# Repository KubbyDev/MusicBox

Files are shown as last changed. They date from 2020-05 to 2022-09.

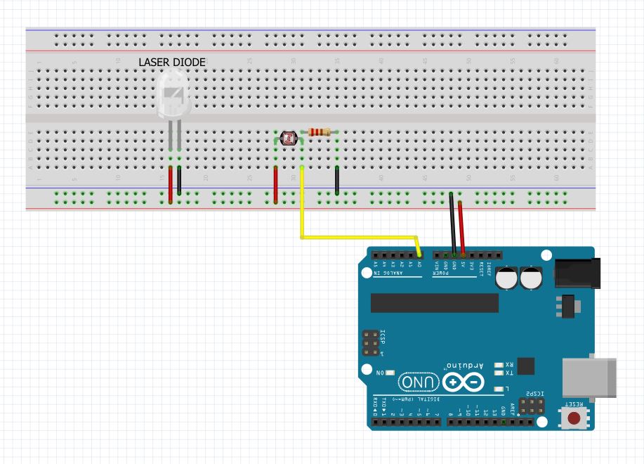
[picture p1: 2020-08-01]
Modules/LaserHarp/Tests/LaserDetection/Circuit.JPG

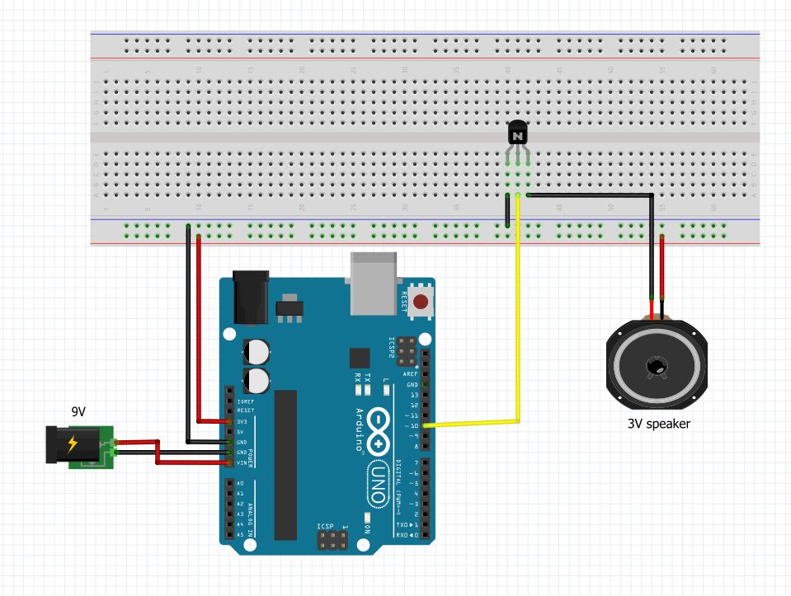
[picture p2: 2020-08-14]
Modules/LaserHarp/Tests/Synthesizing/Circuit.JPG

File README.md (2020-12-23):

# MusicBox

A Music box with only dumb/homemade instruments. Currently I plan on making 5 instruments. All these instruments will be played automatically by the music box from preprocessed files.

### Stepper motors

First prototype done  
Stepper motors (https://www.youtube.com/watch?v=ITn78aMlu0w "Stepper motors")

### Drum

Prototype code is ready to be tested

### Slide Whistle

Some simple prototypes were made but without sufficient performances for the moment.

### Tesla tower

Nothing for the moment

### Laser harp

First prototype in progress

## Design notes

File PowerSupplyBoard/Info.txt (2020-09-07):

General info: 
https://electronics.stackexchange.com/questions/34745/choosing-power-supply-how-to-get-the-voltage-and-current-ratings
Stepper motors: 
https://www.pololu.com/product/1182
http://blog.inventables.com/p/stepper-motors.html

Stepper motors: ---------------------------------------------------------------

Refs:
Quimat 17hd48002h-22b: https://www.amazon.fr/gp/product/B06XQWMDWT/ref=ox_sc_act_title_6?smid=A1WTMON4PWYMJU&psc=1
Longruner A4988: https://www.amazon.fr/gp/product/B071P41ZBW/ref=ox_sc_act_title_1?smid=A1QYNW8GSP8HVC&psc=1

Motor driver:
Voltage for motor: 8V to 35V *
Voltage for logic: 3.3V or 5V
Current draw: 0.5A **
With 3 motors in parallel and a 12V supply, it only draws 0.6A from the supply :shrug:

(*):
There can be voltage spikes higher than 35V, even with a 12V power supply 
These spikes can damage the board. To reduce that risk, connect vmot and gnd with
a 47µF or more capacitor

(**) IMPORTANT: 
Tweak the potentiometer to set the max current (Rsense = 0.1 Ohm)
(read current limiting section: https://www.pololu.com/product/1182)
The value of 0.5A is less than the max (1.7A) and sufficient to get decent melodies

Big Servos --------------------------------------------------------------------

Refs: 
Morza MG996R: https://www.amazon.fr/gp/product/B07KFBWSSW/ref=ox_sc_act_title_3?smid=A3764XWR7FEFWJ&psc=1

Voltage: 4.8V to 7.2V
Current (my measures, 6V): 1A (no load) 2A (stall)

Important: Servo GND and logic GND must be connected

Small Servos ------------------------------------------------------------------

Refs:
SG90

Voltage: 4.8V to 6.0V (best: 5V)
Current (my measures, 5V): 250mA (no load), 700mA (stall)

Important: Servo GND and logic GND must be connected

Laser diodes ------------------------------------------------------------------

Refs:
CESFONJER 650nm 5mW: https://www.amazon.fr/WPERSUVV-Laser-diode-T%C3%AAte-Rouge/dp/B07RM3RWSF

Voltage: 5V
Current (my measures, 5V): 33mA (0.4A for all 12 lasers)

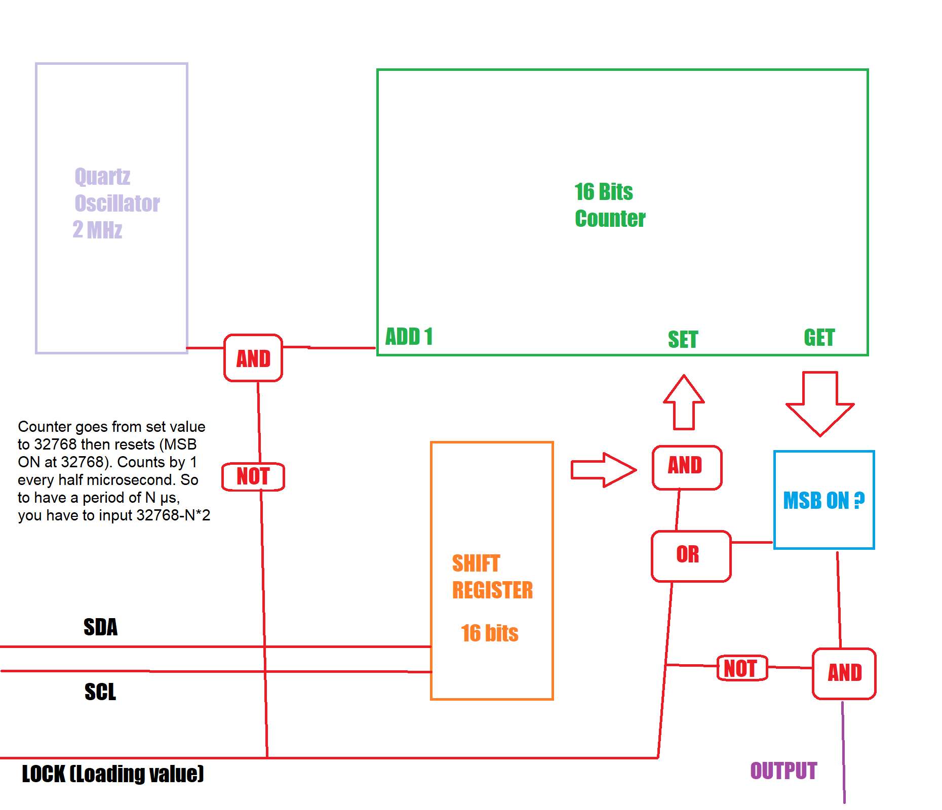
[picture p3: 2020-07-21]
Modules/StepperMotors/OscillatorBoard/Concept2.png

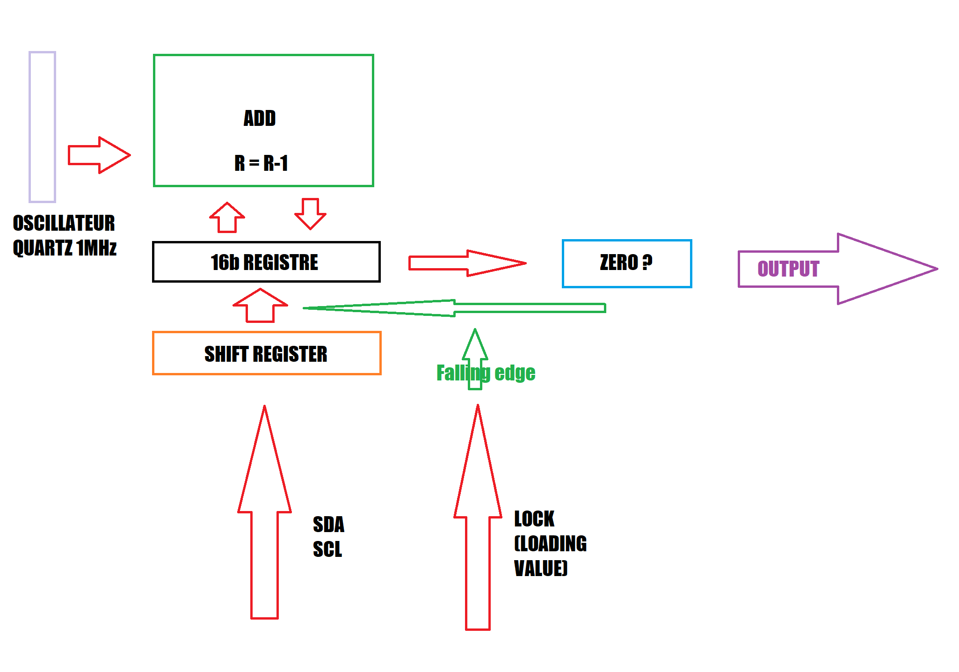
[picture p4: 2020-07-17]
Modules/StepperMotors/OscillatorBoard/Concept1.png

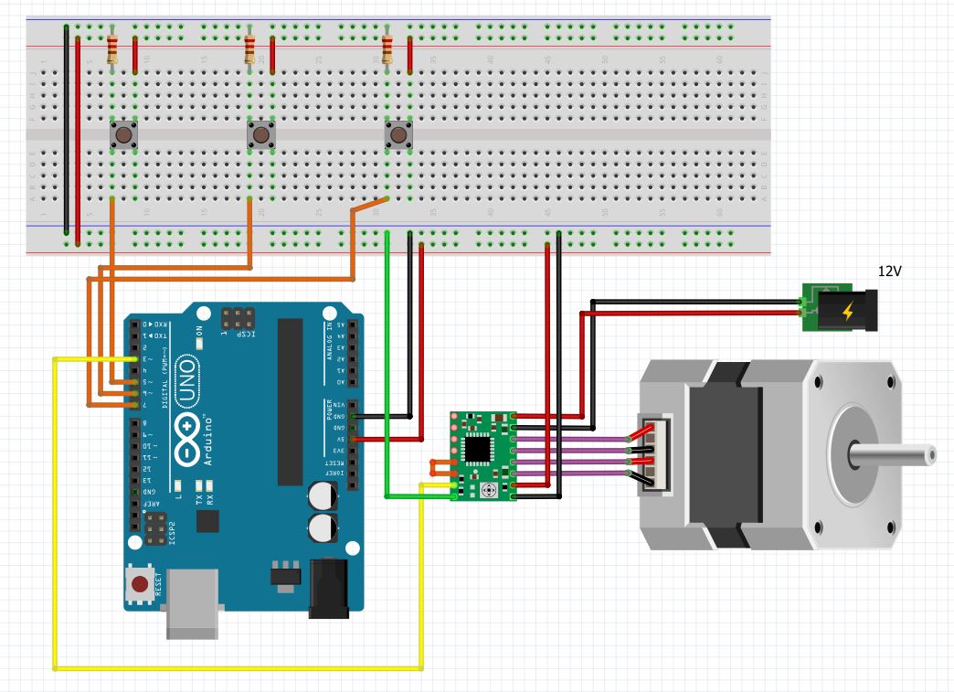
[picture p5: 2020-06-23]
Modules/StepperMotors/Tuner/Circuit.jpg

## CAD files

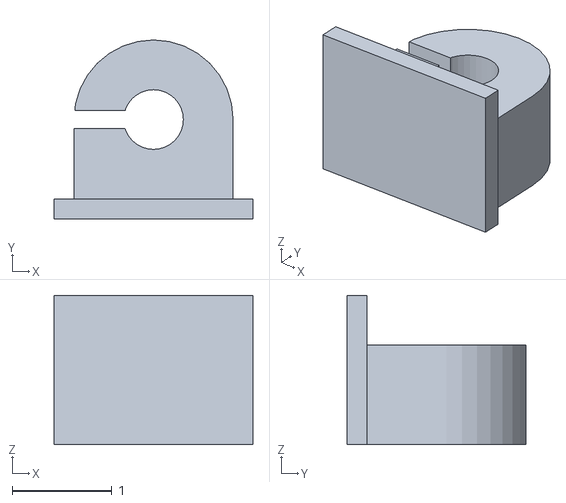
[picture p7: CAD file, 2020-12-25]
Modules/LaserHarp/Hardware/Prototype/laserholder.stl
2.00 x 1.80 x 1.50

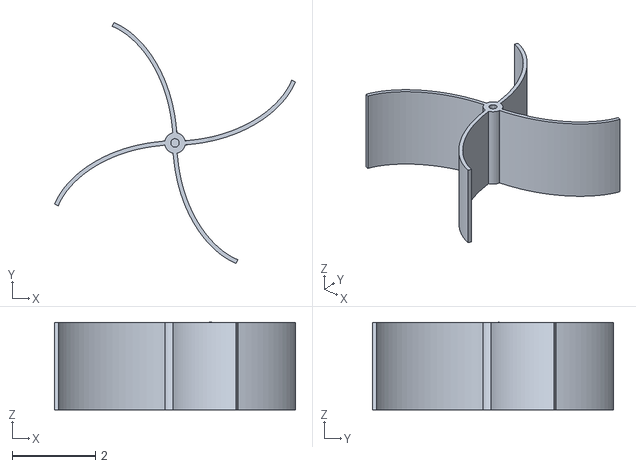
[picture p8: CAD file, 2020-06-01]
Modules/Whistle/Models/Air Blower/Blades.stl
5.80 x 5.80 x 2.11

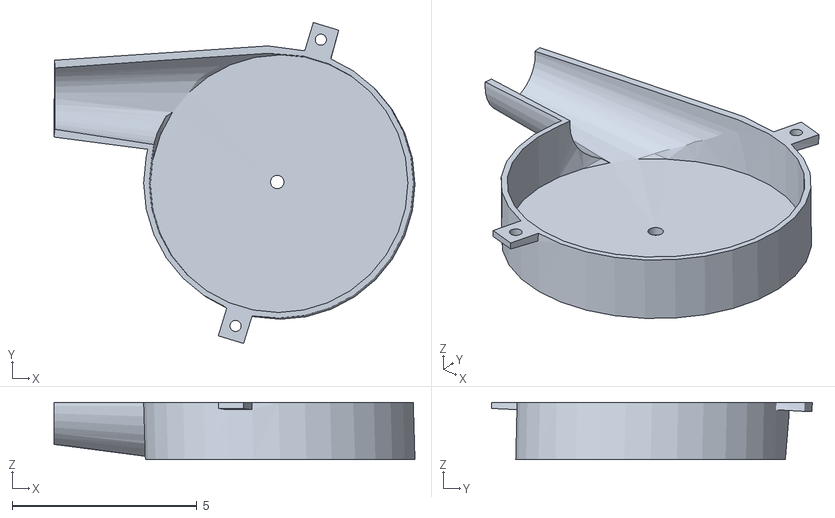
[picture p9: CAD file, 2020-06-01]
Modules/Whistle/Tests/Air Blower/Bottom.stl
9.76 x 8.68 x 1.55

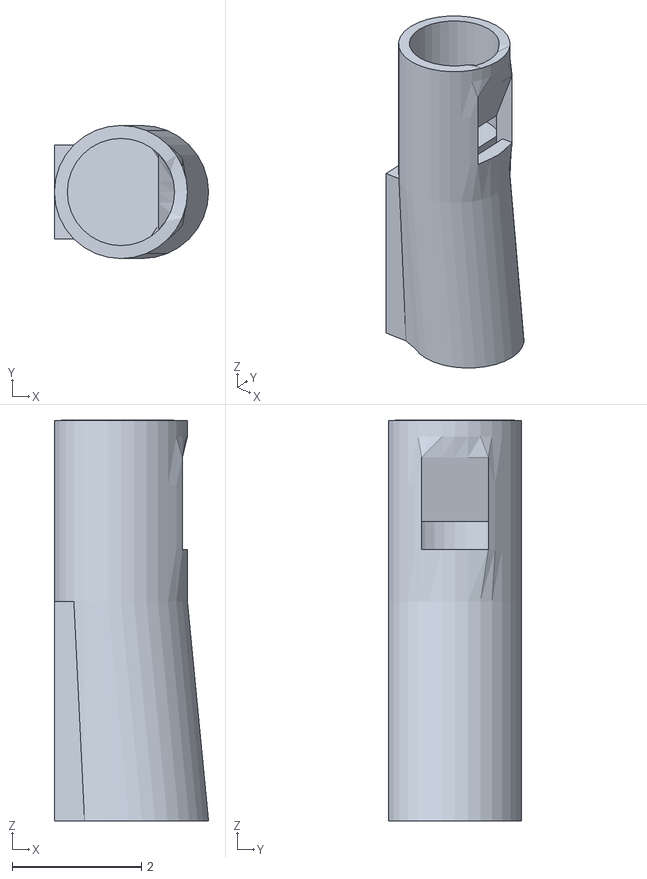
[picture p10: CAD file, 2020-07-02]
Modules/Whistle/Tests/Slide Whistle/V2/Whistle.stl
2.39 x 2.06 x 6.21

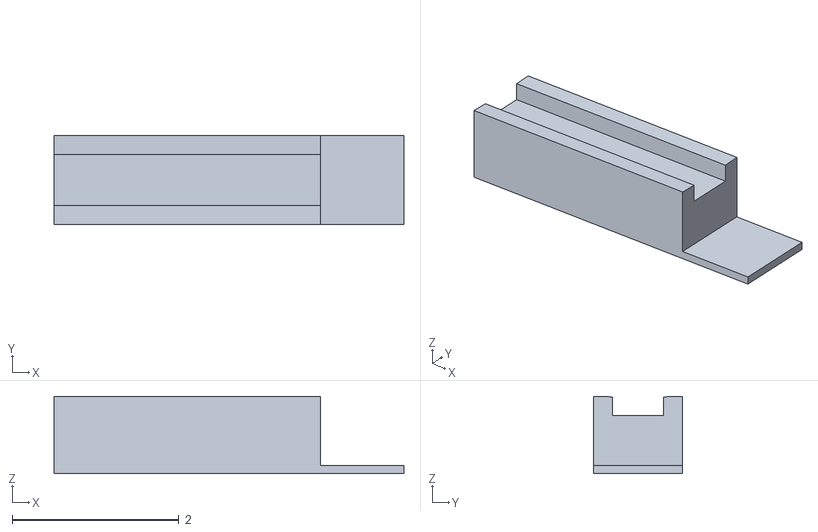
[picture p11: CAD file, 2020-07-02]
Modules/Whistle/Tests/Slide Whistle/V2/Support.stl
4.20 x 1.06 x 0.93

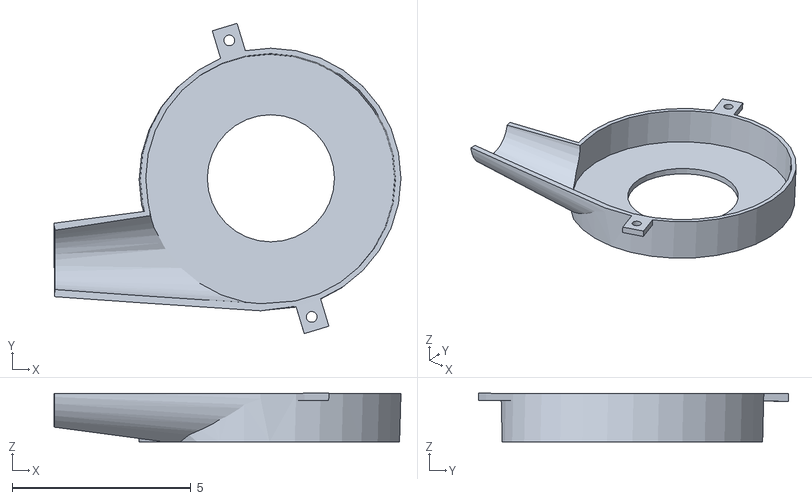
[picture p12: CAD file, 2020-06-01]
Modules/Whistle/Models/Air Blower/Top.stl
9.71 x 8.69 x 1.36

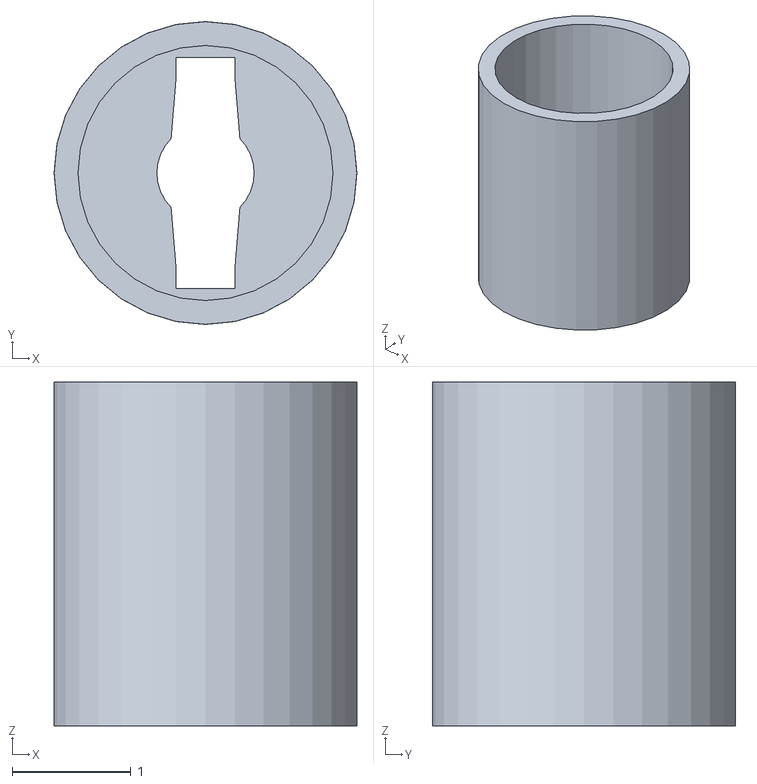
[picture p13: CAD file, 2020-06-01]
Modules/Whistle/Tests/Air Blower/MotorHolder.stl
2.55 x 2.55 x 2.90

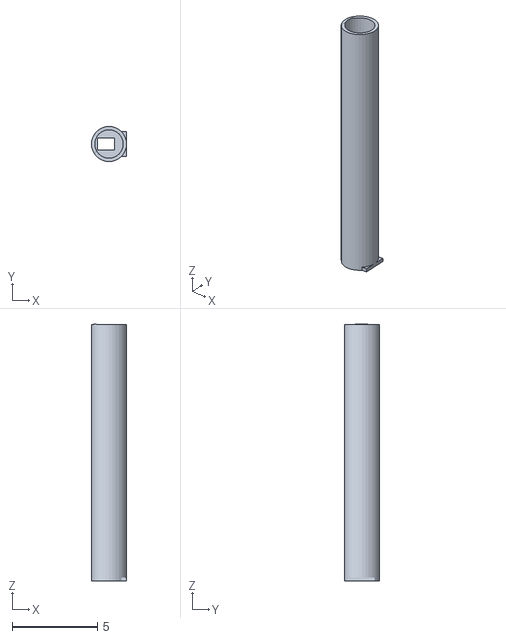
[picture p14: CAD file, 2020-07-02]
Modules/Whistle/Tests/Slide Whistle/V2/Tube.stl
2.06 x 2.06 x 15.0

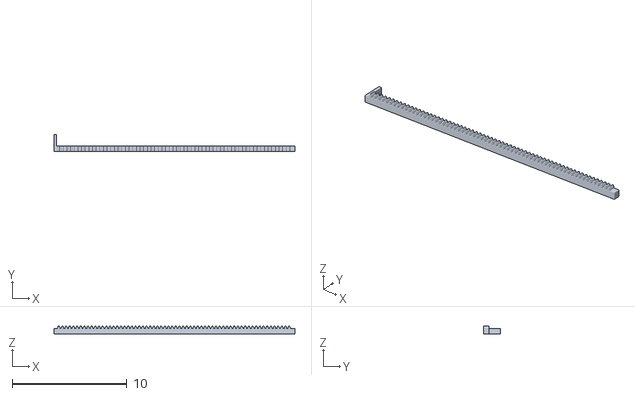
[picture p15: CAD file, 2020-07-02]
Modules/Whistle/Tests/Slide Whistle/V2/Rack.stl
21.0 x 1.50 x 0.711

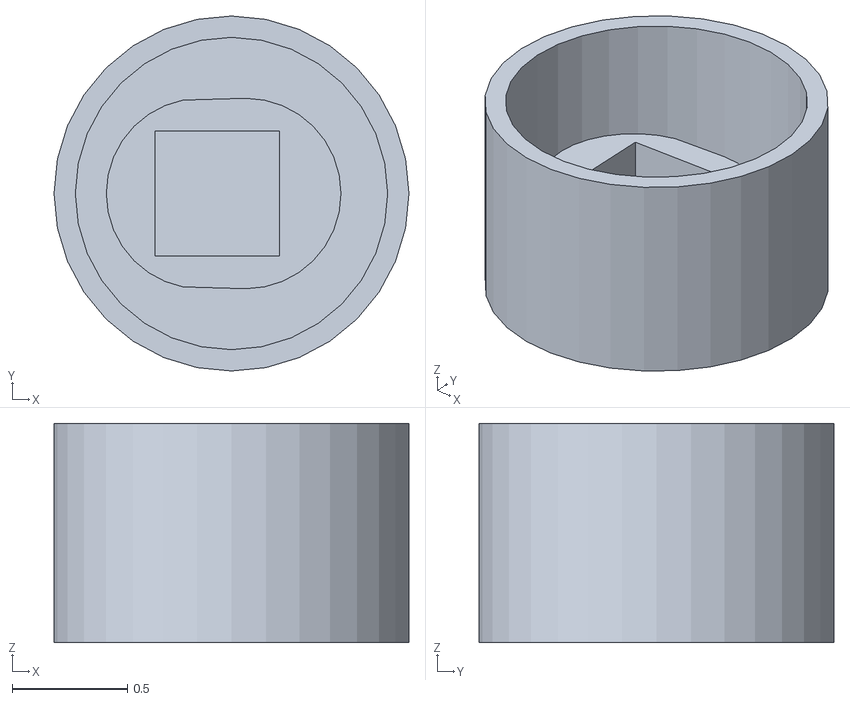
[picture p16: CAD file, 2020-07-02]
Modules/Whistle/Tests/Slide Whistle/V2/Piston.stl
1.54 x 1.54 x 0.95

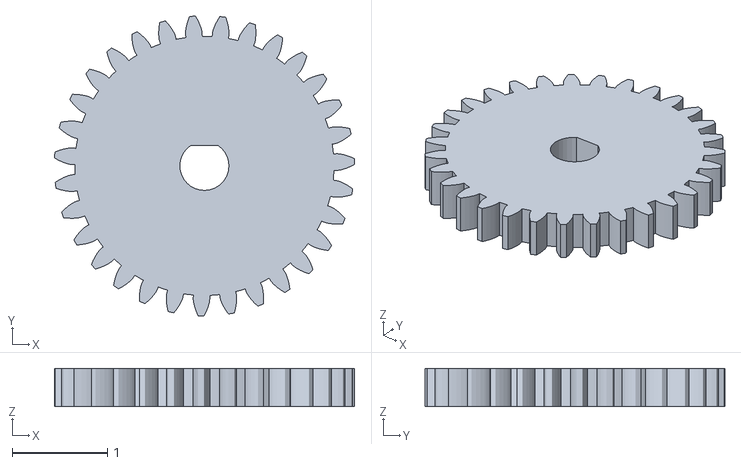
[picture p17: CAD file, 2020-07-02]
Modules/Whistle/Tests/Slide Whistle/V2/Pinion.stl
3.15 x 3.15 x 0.4

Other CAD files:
Modules/LaserHarp/Hardware/Prototype/laserholder.blend
Modules/Whistle/Models/Air Blower/All.blend
Modules/Whistle/Tests/Air Blower/All.blend
Modules/Whistle/Tests/Slide Whistle/V1/Model.blend
Modules/Whistle/Tests/Slide Whistle/V2/Model.blend

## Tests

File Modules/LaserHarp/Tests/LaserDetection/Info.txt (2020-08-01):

No need for a resistor, the laser diodes can be powered directly from 5V (there is an integrated resistor of 91 Ohm)
The lens is focusable

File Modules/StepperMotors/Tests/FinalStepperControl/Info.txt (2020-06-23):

I have this motor: Quimat 17hd48002h-22b
https://www.amazon.co.uk/Quimat-Stepper-Bipolar-Connector-Mounting/dp/B06XQWMDWT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

And this driver: Longruner A4988
https://www.amazon.fr/gp/product/B071P41ZBW/ref=ox_sc_act_title_1?smid=A1QYNW8GSP8HVC&psc=1

With 5V the speed the motor can reach is not great. I had a 12V 500mA power supply so I tried it with much better results
I think the max speed can be further improved using a power supply that can provide 1A (the motor is rated for 1.7A)

Resources:
https://howtomechatronics.com/tutorials/arduino/how-to-control-stepper-motor-with-a4988-driver-and-arduino/

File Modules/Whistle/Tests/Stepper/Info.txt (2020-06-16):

Initially I wanted to use the 28BYJ-48 but I broke it.
So I dissassembled and repaired it, but lost one of the gears in the process
So I just used a JM-24BYJ found in a camera

Resistances (Omh):
Brown - Red: 21
Brown - Blue: 42
Brown - Black: 42
Brown - Yellow: 42
Blue - Black: 42
Blue - Yellow: 42
Blue - Red: 21
Red - Yellow: 21
Red - Black: 21
Yellow - Black: 42

Interpretation:

          Blue
           |
           ||
           |
Brown -=- Red -=- Black
           |
           ||
           |
         Yellow

The order of the wires on the motor is Black Yellow Red Blue Brown. So probably:
Br   Blu Bla    Y
|  R  |   |  R  |
\-/¨\-/   \-/¨\-/

But I didn't manage to make it work :/

So I went back to the 28BYJ-48
I noticed the central shaft holding the rotor was bent, so I put it in place and decided to test it without the gear reduction.
But the motor was getting stuck any ways and didn't have enough power to properly push the piston

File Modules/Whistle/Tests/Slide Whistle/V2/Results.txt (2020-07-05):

Sounds much better be still can't reach the minimum of one octave (I only get D# to G).
Causes:
 - The separation between the tubes should be as far as possible from the whistle. When it was centered it messed everything up, now it only messes up the high notes.
 - The piston leaks air, I think the notes would be clearer if it didn't
 
Other improvements:
 - The rack hole is too wide, it doesn't help it stay centered
 
Tests to do:
 - Put something to prevent air leakage around the piston
 - Test the gear system

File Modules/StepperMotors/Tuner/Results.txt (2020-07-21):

#define A3 4489 // LA
#define A3d 4239 // LA#
#define B3 4001 // SI

#define C4 3778 // DO
#define C4d 3567 // DO#
#define D4 3363 // RE
#define D4d 3175 // RE#
#define E4 2995 // MI
#define F4 2825 // FA
#define F4d 2674 // FA#
#define G4 2515 // SOL
#define G4d 2375 // SOL#
#define A4 2243 // LA
#define A4d 2112 // LA#
#define B4 1996 // SI

#define C5 1886 // DO
#define C5d 1776 // DO#
#define D5 1678 // RE
#define D5d 1584 // RE#
#define E5 1495 // MI
#define F5 1409 // FA
#define F5d 1328 // FA#
#define G5 1252 // SOL
#define G5d 1182 // SOL#
#define A5 1116 // LA
#define A5d 1053 // LA#
#define B5 993 // SI

#define C6 936 // DO

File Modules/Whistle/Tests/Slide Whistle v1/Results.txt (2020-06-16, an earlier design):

Lots of problems

I had to cut/file some pieces, especially the gears supports (I forgot to add a way to put them in :/)
The measurements on the real flute were good because the printed part sounds exactly like the real one
But the piston mechanism (not the gears, just the piston) is awful. There is only one spot where the sound is pretty stable and really changes as the piston moves.
But the range of this spot is from F6 to G6 :/

Causes: I think there are 4 problems:
I filed the separation between the tubes so the piston doesn't get stuck. But maybe this changes the sound. I should print the entire tube at once
The piston probably lets air go past it. I should find a way to get better isolation without getting too much friction
It seems that the whislte should be as free to move as possible to produce a good sound. So I should use some sort of pillars instead of gluing it to the support.
I think the air blower isn't powerful enough because the sound is clearer when I blow in it instead of using the air blower.

Next steps
test the blockig mechanism and maybe break one on the borders of the hole (to make blocking easier) to see if it changes the sound
test the gears mechanism to hopefully learn something from it, then restart from scratch

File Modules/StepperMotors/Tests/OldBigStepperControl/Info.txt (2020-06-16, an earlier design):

Couldn't find any information about this old stepper motor I found in my fathers garage
I had to figure it out by myself:

Wires:
White (WH), Black (BK), Red (RD), Red White (RW), Blue White (BW), Blue (BL)

Information written on the motor:
TYPE 103G775-2142
DC 5.6V
0.6A
1.8 DEG/STEP

Resistances (Ohm):
WH - BW: 10
WH - BL: 10
BW - BL: 20
BK - RW: 10
BK - RD: 10
RW - RD: 20

Interpretation:

BW    BL  RW    RD
|  WH |   |  BK |
\-/¨\-/   \-/¨\-/

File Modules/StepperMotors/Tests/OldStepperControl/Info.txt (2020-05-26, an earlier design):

Couldn't find any information about this old stepper motor I found in my fathers garage
I had to figure it out by myself:

Wires:
Brown, Black, Yellow, Orange, Red, Red2

Information written on the motor:
Volt: 12
Phase: 4
Ohm/Coil: 25
Deg/Step: 7.5
Sankyo HH7-1166
MSAE048C56

Resistances (Omh):
Brown - Black: 50
Yellow - Orange: 50
Red - Brown: 25
Red - Black: 25
Red2 - Yellow: 25
Red2 - Orange: 25

Interpretations:
2 coils:

Br    Bl  O     Y
|  R  |   |  R2 |
\-/¨\-/   \-/¨\-/

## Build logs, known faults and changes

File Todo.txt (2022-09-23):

Music Box:
- Steppers
    Designer la oscillator board
    Faire des recherches/tests pour la caisse de raisonnance
    Visuel: Tourelles de portal
- Slide Whistle
    Ajouter blades + ameliorer efficacité + accroche décrochable pour le moteur
    Trouver un stepper rapide (5 tours/sec minimum) + designer une accroche
    Test complet
- Drum
    Recherches sur la représentation des drums dans les fichiers midi
    Faire un code de generation basique (sans simultanéité)
    Trouver ou acheter un truc qui marche bien comme tambour
    Acheter une cymbale
- Laser harp
	Etudier le besoin et faire la carte de control des lasers si besoin (thermal runaway + découplage)
    Finir la V1
    Recherches/Tests sur le systeme de fumée
	Faire le design mecanique
- Tesla coil
    Recherches
- Power Supply
    Designer la carte de distribution depuis 24V
- Software
    Organiser les instruments avec la subclass
    Mettre des comments ou utiliser des classes pour les structures de données 
    Liste des melodies
    Ameliorer le design de la webapp
    Control des instruments par le serveur
    Serveur de calcul
    Flash Arduino depuis raspi avec un dossier de code
    Append un 0 a la fin des melodies
	Reflechir a une solution pour que les microcontrollers des instruments recuperent les melodies

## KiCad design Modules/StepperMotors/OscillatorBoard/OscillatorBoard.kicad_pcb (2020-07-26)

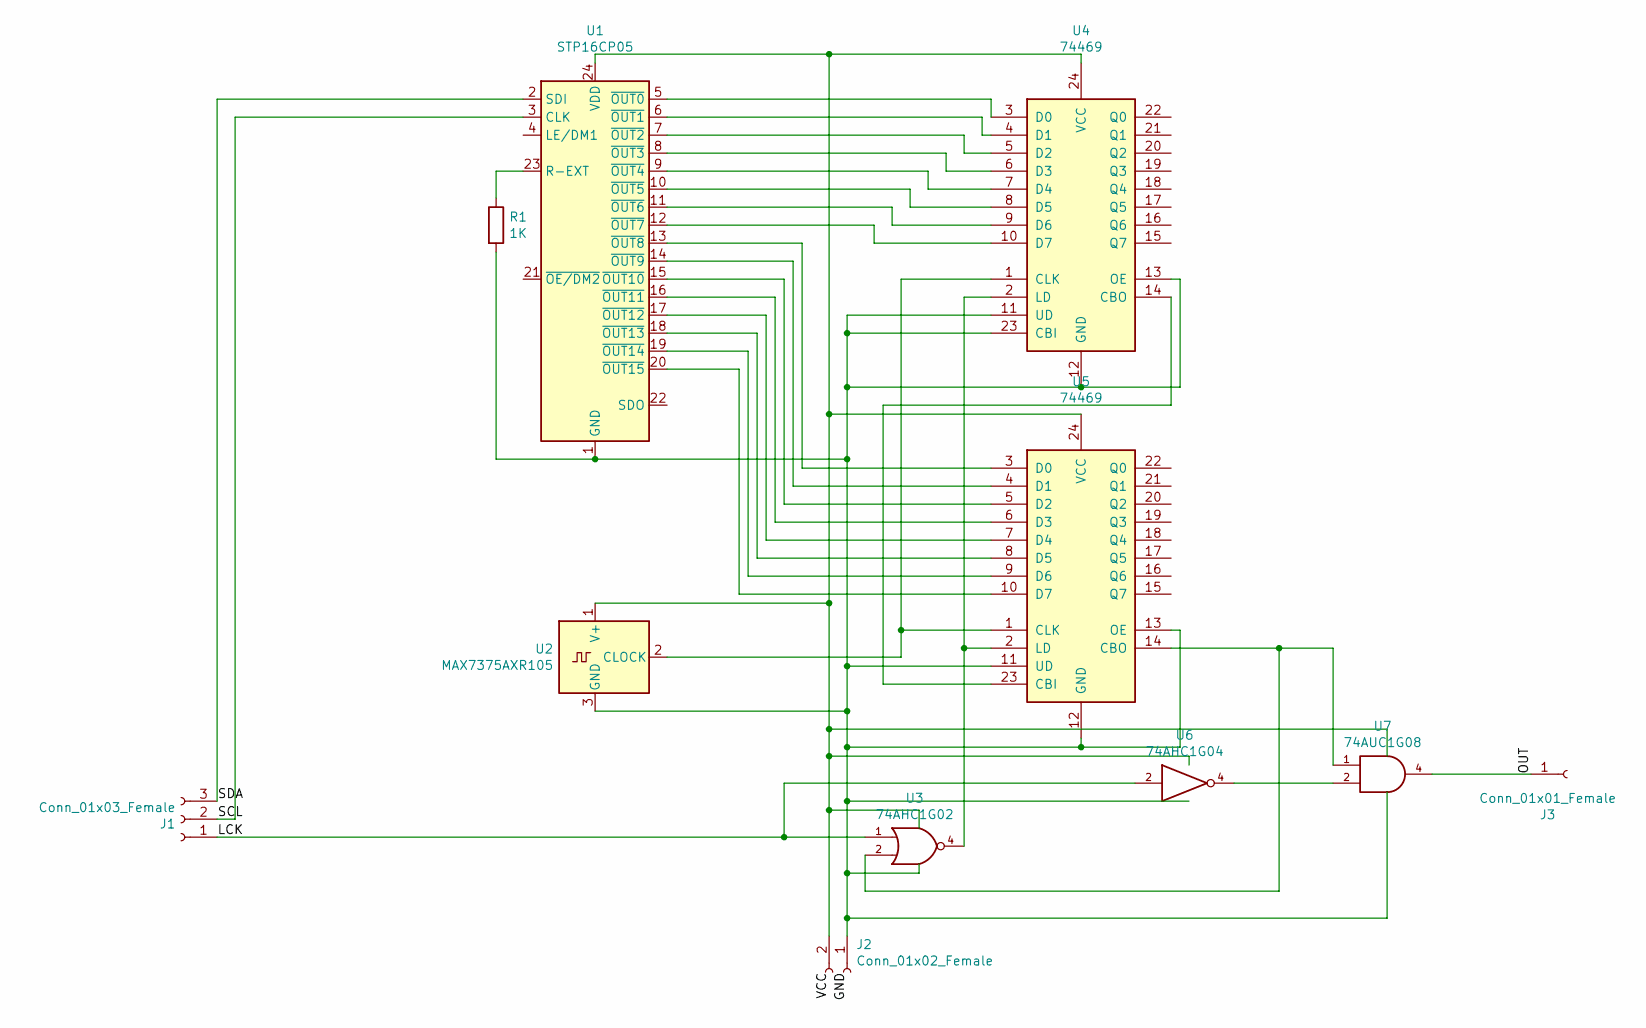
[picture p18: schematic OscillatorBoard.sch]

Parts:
J1: Conn_01x03_Female; PinSocket_1x03_P2.00mm_Vertical
J2: Conn_01x02_Female; PinSocket_1x02_P2.00mm_Vertical
J3: Conn_01x01_Female; PinSocket_1x01_P2.00mm_Vertical
R1: 1K; R_Axial_DIN0204_L3.6mm_D1.6mm_P5.08mm_Horizontal
U1: STP16CP05; QSOP-24_3.9x8.7mm_P0.635mm
U2: MAX7375AXR105; SOT-323_SC-70
U3: 74AHC1G02; SOT-23-5
U4, U5: 74469; DIP-24_W7.62mm
U6: 74AHC1G04; SOT-143
U7: 74AUC1G08; SOT-23-5

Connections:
/LCK: J1.1, U3.1, U6.2
/OUT: J3.1, U7.4
/SCL: J1.2, U1.3 (CLK)
/SDA: J1.3, U1.2 (SDI)
GND: J2.1, R1.2, U1.1 (GND), U2.3 (GND), U3.3 (GND), U4.11 (UD), U4.12 (GND), U4.13 (OE), U4.23 (CBI), U5.11 (UD), U5.12 (GND), U5.13 (OE), U6.3 (GND), U7.3 (GND)
unnamed: R1.1, U1.23 (R-EXT)
unnamed: U1.5 (~OUT0), U4.3 (D0)
unnamed: U1.6 (~OUT1), U4.4 (D1)
unnamed: U1.7 (~OUT2), U4.5 (D2)
unnamed: U1.8 (~OUT3), U4.6 (D3)
unnamed: U1.9 (~OUT4), U4.7 (D4)
unnamed: U1.10 (~OUT5), U4.8 (D5)
unnamed: U1.11 (~OUT6), U4.9 (D6)
unnamed: U1.12 (~OUT7), U4.10 (D7)
unnamed: U1.13 (~OUT8), U5.3 (D0)
unnamed: U1.14 (~OUT9), U5.4 (D1)
unnamed: U1.15 (~OUT10), U5.5 (D2)
unnamed: U1.16 (~OUT11), U5.6 (D3)
unnamed: U1.17 (~OUT12), U5.7 (D4)
unnamed: U1.18 (~OUT13), U5.8 (D5)
unnamed: U1.19 (~OUT14), U5.9 (D6)
unnamed: U1.20 (~OUT15), U5.10 (D7)
unnamed: U2.2 (CLOCK), U4.1 (CLK), U5.1 (CLK)
unnamed: U3.2, U5.14 (CBO), U7.1
unnamed: U3.4, U4.2 (LD), U5.2 (LD)
unnamed: U4.14 (CBO), U5.23 (CBI)
unnamed: U6.4, U7.2
VCC: J2.2, U1.24 (VDD), U2.1 (V+), U3.5 (VCC), U4.24 (VCC), U5.24 (VCC), U6.5 (VCC), U7.5 (VCC)

Board: 2 copper layers, 11 parts (0 on the bottom side), 28 nets, no tracks yet.

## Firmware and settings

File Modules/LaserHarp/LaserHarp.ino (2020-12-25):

#include <Servo.h>

#define NB_LASERS 12
#define NB_SERVOS 6
#define SERVO_LEFT 140
#define SERVO_RIGHT 40
#define SERVO_MID 90
#define SPEAKER_PIN 51

// For a laser to be cut, its tension value must be greater than
// its base value + THRESHOLD_PROP*(1024 - base_value)
#define THRESHOLD_PROP 0.25

const int SERVO_PINS[NB_SERVOS] = {30,32,34,36,38,40};
const int RESISTOR_PINS[NB_LASERS] = {A1,A2,A3,A4,A5,A6,A7,A8,A9,A10,A11,A12};
const int LED_PINS[8] = {24,25,26,27,28,29,30,31};
Servo servos[NB_SERVOS];
#define OCTAVE_UP 32
#define OCTAVE_DOWN 33

unsigned int frequencies[8][12] = {
    { /*C1*/33,/*C#1*/35,/*D1*/37,/*D#1*/39,/*E1*/41,/*F1*/44,/*F#1*/46,/*G1*/49,/*G#1*/52,/*A1*/55,/*A#1*/58,/*B1*/62 },
    { /*C2*/65,/*C#2*/69,/*D2*/73,/*D#2*/78,/*E2*/82,/*F2*/87,/*F#2*/92,/*G2*/98,/*G#2*/104,/*A2*/110,/*A#2*/117,/*B2*/123 },
    { /*C3*/131,/*C#3*/139,/*D3*/147,/*D#3*/156,/*E3*/165,/*F3*/175,/*F#3*/185,/*G3*/196,/*G#3*/208,/*A3*/220,/*A#3*/233,/*B3*/247 },
    { /*C4*/262,/*C#4*/277,/*D4*/294,/*D#4*/311,/*E4*/330,/*F4*/349,/*F#4*/370,/*G4*/392,/*G#4*/415,/*A4*/440,/*A#4*/466,/*B4*/494 },
    { /*C5*/523,/*C#5*/554,/*D5*/587,/*D#5*/622,/*E5*/659,/*F5*/698,/*F#5*/740,/*G5*/784,/*G#5*/831,/*A5*/880,/*A#5*/932,/*B5*/988 },
    { /*C6*/1046,/*C#6*/1109,/*D6*/1175,/*D#6*/1244,/*E6*/1318,/*F6*/1397,/*F#6*/1480,/*G6*/1568,/*G#6*/1661,/*A6*/1760,/*A#6*/1865,/*B6*/1976 },
    { /*C7*/2093,/*C#7*/2218,/*D7*/2349,/*D#7*/2489,/*E7*/2637,/*F7*/2794,/*F#7*/2960,/*G7*/3136,/*G#7*/3322,/*A7*/3520,/*A#7*/3729,/*B7*/3951 },
    { /*C8*/4186,/*C#8*/4435,/*D8*/4699,/*D#8*/4978,/*E8*/5274,/*F8*/5587,/*F#8*/5920,/*G8*/6272,/*G#8*/6644,/*A8*/7040,/*A#8*/7459,/*B8*/7903 }
};

// The notes are encoded as midi pitches
const PROGMEM uint16_t notesHarp[] = { 0, 64, 0, 64, 71, 64, 69, 64, 68, 64, 0, 59, 0, 64, 71, 64, 69, 64, 68, 64, 0, 61, 64, 71, 64, 69, 64, 68, 64, 0, 57, 0, 64, 71, 64, 69, 68, 64, 66, 64, 0, 64, 71, 64, 69, 64, 68, 64, 0, 59, 64, 71, 64, 69, 64, 68, 64, 0, 61, 64, 71, 64, 69, 64, 68, 64, 0, 57, 64, 71, 64, 69, 68, 0, 64, 66, 64, 0, 59, 0, 64, 0, 64, 0, 59, 64, 0, 64, 0, 59, 64, 0, 64, 63, 61, 63, 0, 59, 64, 0, 64, 0, 59, 64, 0, 64, 0, 59, 64, 0, 64, 63, 61, 59, 0, 59, 0, 64, 0, 64, 0, 59, 64, 0, 64, 0, 59, 64, 0, 64, 63, 61, 63, 0, 64, 0, 64, 0, 64, 69, 68, 66, 64, 0, 64, 59, 0, 71, 69, 68, 0, 66, 63, 64, 66, 61, 71, 69, 68, 0, 64, 0, 64, 66, 68, 64, 0, 71, 69, 68, 0, 66, 63, 64, 66, 61, 0, 71, 69, 68, 0, 64, 0, 64, 66, 68, 64, 59, 0, 71, 69, 68, 0, 66, 63, 64, 66, 61, 71, 69, 68, 0, 64, 0, 64, 66, 68, 64, 0, 71, 69, 68, 0, 66, 63, 64, 66, 61, 0, 71, 69, 68, 0, 64, 0, 64, 66, 68, 64, 0 };
const PROGMEM uint32_t timesHarp[] = { 0, 398, 615, 638, 866, 1093, 1320, 1547, 1775, 2002, 2229, 2231, 2449, 2456, 2684, 2911, 3138, 3366, 3593, 3820, 4047, 4068, 4275, 4502, 4728, 4955, 5183, 5409, 5637, 5865, 5870, 6086, 6092, 6319, 6546, 6774, 7001, 7228, 7455, 7669, 7874, 7898, 8137, 8365, 8592, 8819, 9046, 9274, 9501, 9523, 9728, 9955, 10183, 10409, 10637, 10865, 11092, 11319, 11343, 11546, 11774, 12001, 12228, 12455, 12683, 12909, 13137, 13168, 13365, 13592, 13819, 14046, 14274, 14501, 14516, 14728, 14937, 15152, 15197, 15398, 15438, 15628, 15665, 16101, 16132, 16373, 16591, 16601, 17010, 17056, 17283, 17500, 17510, 17965, 18192, 18419, 18829, 18873, 19101, 19319, 19329, 19738, 19783, 20010, 20228, 20238, 20647, 20692, 20919, 21137, 21147, 21601, 22056, 22317, 22478, 22510, 22718, 22738, 22955, 22965, 23373, 23419, 23647, 23863, 23873, 24283, 24329, 24556, 24773, 24783, 25238, 25465, 25692, 26306, 26373, 26591, 26601, 28023, 28192, 28419, 28873, 29329, 29783, 30000, 30010, 30465, 30704, 30919, 31373, 31601, 32010, 32056, 32738, 32965, 33419, 33873, 34556, 35010, 35238, 35647, 35692, 36363, 36373, 36601, 37056, 37510, 38123, 38192, 38647, 38873, 39283, 39329, 40010, 40238, 40692, 41147, 41760, 41829, 42283, 42510, 42919, 42965, 43637, 43647, 43873, 44329, 44783, 45010, 45248, 45465, 45919, 46147, 46556, 46601, 47283, 47510, 47965, 48419, 49101, 49556, 49783, 50192, 50238, 50909, 50919, 51147, 51601, 52056, 52669, 52738, 53192, 53419, 53829, 53873, 54556, 54783, 55238, 55692, 56306, 56373, 56829, 57056, 57465, 57510, 58182, 58192, 58419, 58873, 59329, 59500 };

int currentOctave = 4;
int octaveUpPressed = 0;
int octaveDownPressed = 0;
int index = 0;

int thresholds[NB_LASERS];

void setup() {

    delay(2000);
    
    Serial.begin(115200);
    
    // Servos
    for(unsigned int i = 0; i < sizeof(SERVO_PINS)/sizeof(int); i++) {
        int pin = SERVO_PINS[i];
        pinMode(pin, OUTPUT);
        servos[i].attach(pin);
        servos[i].write(SERVO_MID);
    }
    delay(50);
    // Photoresistors
    for(unsigned int i = 0; i < sizeof(RESISTOR_PINS)/sizeof(int); i++) {
        pinMode(RESISTOR_PINS[i], INPUT);
        int base_value = 0;
        for(int j = 0; j < 3; j++) {
          base_value += analogRead(RESISTOR_PINS[i]);
          delay(10);
        }
        base_value /= 3;
        thresholds[i] = THRESHOLD_PROP * (1024 - base_value) + base_value;
        Serial.print("Threshold ");
        Serial.print(i);
        Serial.print(": ");
        Serial.println(thresholds[i]);
    }
    // Leds
    for(unsigned int i = 0; i < sizeof(LED_PINS)/sizeof(int); i++)
        pinMode(LED_PINS[i], OUTPUT);
    // Others
    pinMode(SPEAKER_PIN, OUTPUT);
    pinMode(OCTAVE_UP, INPUT);
    pinMode(OCTAVE_DOWN, INPUT);

    digitalWrite(LED_BUILTIN, LOW);
    delay(500);
    digitalWrite(LED_BUILTIN, HIGH);
    delay(500);
    digitalWrite(LED_BUILTIN, LOW);
    delay(500);
    digitalWrite(LED_BUILTIN, HIGH);
    delay(500);
    digitalWrite(LED_BUILTIN, LOW);
}

void loop() {

    long m = millis();

    while(millis() - m < 50)
      controlLoop();
    
    harpLoop();
}

// Changes the currently selected octave. Can be called
// by the control loop or by the harp loop (buttons)
void changeOctave(int octave) {
    for(int i = 1; i <= 8; i++)
        digitalWrite(LED_PINS[i-1], i == octave);
    currentOctave = octave;
}

// Harp section -----------------------------------------------------------------------

// Finds the laser that is being cut if there is one 
// Returns the index of the laser, -1 if no laser is cut
int findCutLaser() {
  
    int res = NB_LASERS-1;
    while(res >= 0 && analogRead(RESISTOR_PINS[res]) < thresholds[res])
        res--;
    return res;
}

// Plays the given note for 75 ms
void playNote(int note) {
    int oct = note/12 -1;
    int nte = note%12;
    int freq = frequencies[oct-1][nte];
    tone(SPEAKER_PIN,freq,75);
}

// Checks the octave control buttons and changes the current octave if necessary
void changeOctaveButtons() {
    
    if(!octaveUpPressed && digitalRead(OCTAVE_UP)) {
        changeOctave(currentOctave+1);
        octaveUpPressed = 1;
    }
    else octaveUpPressed = 0;
    
    if(!octaveDownPressed && digitalRead(OCTAVE_DOWN)) {
        changeOctave(currentOctave-1);
        octaveDownPressed = 1;
    }
    else octaveDownPressed = 0;
}

// Part of the loop function that handles the harp 
// (finding what laser is being cut and playing the appropriate sound)
void harpLoop() {
    
    for(int i = 0; i < 12; i++) {
        Serial.print(thresholds[i]);
        Serial.print(": ");
        Serial.println(analogRead(RESISTOR_PINS[i]));
    }
    
    int cutLaser = findCutLaser();
    if(cutLaser >= 0) {
        digitalWrite(LED_BUILTIN, HIGH);
        int note = 12*(currentOctave+1) + cutLaser;
        playNote(note);
    }
    else
        digitalWrite(LED_BUILTIN, LOW);

    Serial.println("-------------------------");
}

// Control section --------------------------------------------------------------------

void changeNote(int note) {

    int toUse = -1; // Index of the servo that will cut a laser
    
    if(note != 0) {
        changeOctave(note/12); // Changes the octave if there is a note to play
        toUse = (note%12)/2;
    }

    for(int i = 0; i < NB_SERVOS; i++) {
        if(i != toUse) {
            servos[i].write(SERVO_MID);
            continue;
        }
        servos[i].write(note%2 == 0 ? SERVO_RIGHT : SERVO_LEFT);
    }
}

void controlLoop() {
    
    unsigned long now = millis();
    
    if(now > pgm_read_dword(timesHarp + index)) {
        changeNote(pgm_read_word(notesHarp + index));
        index++;
    }
}

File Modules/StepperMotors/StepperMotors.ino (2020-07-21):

// Step pin of each motor driver
#define M1 3
#define M2 4
#define M3 5

#define A3 4489 // LA
#define A3d 4239 // LA#
#define B3 4001 // SI

#define C4 3778 // DO
#define C4d 3567 // DO#
#define D4 3363 // RE
#define D4d 3175 // RE#
#define E4 2995 // MI
#define F4 2825 // FA
#define F4d 2674 // FA#
#define G4 2515 // SOL
#define G4d 2375 // SOL#
#define A4 2243 // LA
#define A4d 2112 // LA#
#define B4 1996 // SI

#define C5 1886 // DO
#define C5d 1776 // DO#
#define D5 1678 // RE
#define D5d 1584 // RE#
#define E5 1495 // MI
#define F5 1409 // FA
#define F5d 1328 // FA#
#define G5 1252 // SOL
#define G5d 1182 // SOL#
#define A5 1116 // LA
#define A5d 1053 // LA#
#define B5 993 // SI

#define C6 936 // DO

const PROGMEM uint16_t notes1[] = {
    0,D5,0,D5,0,D5,0,D5,0,D5,0,D5,0,C5,0,A4d,0,A4d,0,A4d,0,A4d,0,A4,0,A4,0,A4,0,A4,0,D5,0,D5,0,D5,0,D5,0,A4d,0,A4d,0,A4d,0,A4d,0,A4d,0,A4d,0,A4d,0,A4d,0,A4,0,A4,0,A4,0,A4,0,D5,0,D5,0,D5,0,D5,0,D5,0,D5,0,D5,0,D5,0,A4d,0,A4d,0,A4d,0,A4d,0,G4,0,G4,0,G4,0,G4,0,D5,0,D5,0,D5,0,D5,0,A4d,0,A4d,0,A4d,0,A4d,0,D5,0,D5,0,D5,0,D5,0,A4,0,A4,0,A4,0,A4,0,A4,0,A4,0,A4,0,A4,0,D5,0,D5,0,D5,0,C5,0,A4d,0,A4d,0,A4d,0,A4d,0,A4,0,A4,0,A4,0,A4,0,D5,0,D5,0,D5,0,D5,0,A4d,0,A4d,0,A4d,0,A4d,0,F4,0,F4,0,F4,0,F4,0,C5,0,C5,0,A4,0,A4,0,D5,0,D5,0,D5,0,D5,0,D5,0,D5,0,D5,0,D5,0,A4d,0,A4d,0,A4d,0,A4d,0,G4,0,G4,0,G4,0,G4,0,D5,0,D5,0,D5,0,D5,0,A4d,0,A4d,0,A4d,0,A4d,0,D5,0,D5,0,D5,0,D5,0,A4,0,A4,0,A4,0,A4,0,D5,0,D5,0,C5,0,C5,0,C5,0,A4d,0,A4,0,A4,0,A4,0,A4,0,A4,0,A4,0,A4,0,A4,0,G4,0,G4,0,G4,0,G4,0,G4,0,G4,0,G4,0,G4,0,A4,0,A4,0,A4,0,A4,0,A4,0,A4,0,A4,0,A4,0,D5,0,D5,0,D5,0,D5,0,D5,0,D5,0,D5,0,D5,0,D5,0,C5,0,C5,0,C5,0,C5,0,F5,0,F5,0,F5,0,F5,0,F5,0,D5,0,D5,0,D5,0,D5,0,D5,0,D5,0,D5,0,D5,0,D5,0,A4,0,A4,0,A4,0,A4,0,D5,0,D5,0,D5,0,D5,0,D5,0,D5,0,D5,0,D5,0,C5,0,C5,0,C5,0,C5,0,C5,0,F5,0,F5,0,F5,0,F5,0,F5,0,C5,0,C5,0,C5,0,C5,0,C5,0,F5,0,F5,0,F5,0,F5,0,F5,0,A4,0,A4,0,A4,0,A4,0,A4,0,D5,0,D5,0,D5,0,D5,0,D5,0,D5,0,D5,0,D5,0,D5,0,D5,0,D5,0,D5,0,D5,0,D5,0,C5,0,C5,0,C5,0,C5,0,C5,0,F5,0,F5,0,F5,0,F5,0,F5,0,A4d,0,A4d,0,A4d,0,A4d,0,A4d,0,D5,0,D5,0,D5,0,D5,0,D5,0,G4,0,G4,0,G4,0,G4,0,G4,0,A4,0,A4,0,A4,0,A4,0,A4,0,A4,0,A4,0,A4,0,A4,0,A4,0,D5,0,D5,0,D5,0,D5,0,D5,0,G4,0,G4,0,G4,0,G4,0,G4,0,F5,0,F5,0,F5,0,F5,0,C5,0,C5,0,C5,0,C5,0,C5,0,G4,0,G4,0,G4,0,G4,0,G4,0,A4,0,A4,0,A4,0,A4,0,A4,0,A4,0,A4,0,A4,0,A4,0,A4,0,D5,0,D5,0,D5,0,D5,0,D5,0,D5,0,D5,0,D5,0,D5,0,D5,0,A4d,0,A4d,0,A4d,0,A4d,0,A4d,0,F5,0,F5,0,F5,0,F5,0,F5,0,C5,0,C5,0,C5,0,C5,0,C5,0,G4,0,G4,0,G4,0,G4,0,G4,0,A4,0,A4,0,A4,0,A4,0,A4,0,A4,0,A4,0,A4,0,A4,0,A4,0,D5,0,D5,0,D5,0,D5,0,D5,0
};
const PROGMEM uint32_t durations1[] = {
    3600,4425,4500,4900,4950,5350,5400,5650,5700,5847,5850,6100,6150,6297,6300,6550,6600,6747,6750,7000,7050,7197,7200,7450,7500,7647,7650,7900,7950,8097,8100,8350,8400,8547,8550,8800,8850,8997,9000,9250,9300,9447,9450,9700,9750,9897,9900,10150,10200,10347,10350,10600,10650,10797,10800,11050,11100,11247,11250,11500,11550,11697,11700,11950,12000,12147,12150,12400,12450,12597,12600,12850,12900,13047,13050,13300,13350,13497,13500,13750,13800,13947,13950,14200,14250,14397,14400,14650,14700,14847,14850,15100,15150,15297,15300,15550,15600,15747,15750,16000,16050,16197,16200,16450,16500,16647,16650,16900,16950,17097,17100,17350,17400,17547,17550,17800,17850,17997,18000,18250,18300,18447,18450,18700,18750,18897,18900,19150,19200,19347,19350,19600,19650,19797,19800,20050,20100,20247,20250,20500,20550,20697,20700,20950,21000,21147,21150,21400,21450,21597,21600,21850,21900,22047,22050,22300,22350,22497,22500,22750,22800,22947,22950,23200,23250,23397,23400,23650,23700,23847,23850,24100,24150,24297,24300,24550,24600,24747,24750,25000,25050,25197,25200,25450,25500,25647,25650,25900,25950,26097,26100,26350,26400,26547,26550,26800,26850,26997,27000,27250,27300,27447,27450,27700,27750,27897,27900,28150,28200,28347,28350,28600,28650,28797,28800,29050,29100,29247,29250,29500,29550,29697,29700,29950,30000,30147,30150,30400,30450,30597,30600,30850,30900,31047,31050,31300,31350,31497,31500,31750,31800,31947,31950,32200,32250,32397,32400,32650,32700,32847,32850,33100,33150,33297,33300,33550,33600,33850,33900,34150,34200,34450,34500,34750,34800,35050,35100,35350,35400,35547,35550,35800,35850,35997,36000,36250,36300,36447,36450,36700,36750,36897,36900,37150,37200,37347,37350,37600,37650,37797,37800,38050,38100,38247,38250,38500,38550,38697,38700,38950,39000,39147,39150,39400,39450,39597,39600,39850,39900,40047,40050,40300,40350,40497,40500,40750,40800,40947,40950,41200,41250,41397,41400,41650,41700,41847,41850,41997,42000,42147,42150,42297,42300,42550,42600,42747,42750,43000,43050,43197,43200,43450,43500,43647,43650,43797,43800,43947,43950,44097,44100,44350,44400,44547,44550,44800,44850,44997,45000,45250,45300,45447,45450,45597,45600,45747,45750,45897,45900,46150,46200,46347,46350,46600,46650,46797,46800,47050,47100,47247,47250,47500,47550,47697,47700,47950,48000,48147,48150,48400,48450,48597,48600,48850,48900,49047,49050,49197,49200,49347,49350,49497,49500,49750,49800,49947,49950,50097,50100,50247,50250,50397,50400,50650,50700,50847,50850,50997,51000,51147,51150,51297,51300,51550,51600,51747,51750,51897,51900,52047,52050,52197,52200,52450,52500,52647,52650,52797,52800,52947,52950,53097,53100,53350,53400,53547,53550,53800,53850,53997,54000,54250,54300,54447,54450,54597,54600,54747,54750,54897,54900,55150,55200,55347,55350,55497,55500,55647,55650,55797,55800,56050,56100,56247,56250,56397,56400,56547,56550,56697,56700,56950,57000,57147,57150,57297,57300,57447,57450,57597,57600,57850,57900,58047,58050,58197,58200,58347,58350,58497,58500,58750,58800,58947,58950,59097,59100,59247,59250,59397,59400,59650,59700,59847,59850,59997,60000,60147,60150,60297,60300,60550,60600,60747,60750,60897,60900,61047,61050,61197,61200,61450,61500,61647,61650,61797,61800,61947,61950,62097,62100,62350,62400,62547,62550,62697,62700,62847,62850,62997,63000,63250,63300,63447,63450,63597,63600,63747,63750,63897,63900,64150,64200,64347,64350,64600,64650,64797,64800,65050,65100,65247,65250,65397,65400,65547,65550,65697,65700,65950,66000,66147,66150,66297,66300,66447,66450,66597,66600,66850,66900,67047,67050,67197,67200,67347,67350,67497,67500,67750,67800,67947,67950,68097,68100,68247,68250,68397,68400,68650,68700,68847,68850,68997,69000,69147,69150,69297,69300,69550,69600,69747,69750,69897,69900,70047,70050,70197,70200,70450,70500,70647,70650,70797,70800,70947,70950,71097,71100,71350,71400,71547,71550,71697,71700,71847,71850,71997,72000,72250,72300,72447,72450,72597,72600,72747,72750,72897,72900,73150,73200,73347,73350,73497,73500,73647,73650,73797,73800,74050,74100,74247,74250,74397,74400,74547,74550,74697,74700,74950,75000,75147,75150,75297,75300,75447,75450,75597,75600,76000,76050,76197,76200,76347,76350,76497,76505,77630,4294967295
};
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

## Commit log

2020-05-16 First tests with stepper
2020-06-01 Air Blower model
    [All.blend, Blades.stl, Body.blend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]
2020-06-02 SlideWhistle body v1 almost done
    [All.blend, Blades.stl, Body.blend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]
2020-06-05 SlideWhistle v1
    [Body.blend, FluteBegin.stl, FluteEnd.stl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]
2020-06-12 Slide Whistle fix
    [Body.blend]
2020-06-16 First stepper music
2020-06-16 Slide whistle tests
    [All.blend, Blades.stl, Bottom.stl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]
2020-06-23 StepperMotors module base done
2020-06-25 Better code for steppers (TO TEST)
2020-06-25 Power Supply researches
2020-06-30 Stepper motors module done
2020-07-01 Steppers module v1
2020-07-02 Slide whistle design V2
    [Model.blend, Pinion.stl, Piston.stl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]
2020-07-05 Slide Whistle V2 results + Servo testing
2020-07-17 OscillatorBoard draft
    [OscillatorBoard.kicad_pcb, OscillatorBoard.sch]
2020-07-21 OscillatorBoard Concept2 + First kicad schematic
    [OscillatorBoard.kicad_pcb, OscillatorBoard.sch]
2020-07-22 Simple drum Arduino code
2020-07-25 Started track preprocess interface
2020-07-26 KiCAD tests (Oscillator Board)
    [OscillatorBoard.kicad_pcb, OscillatorBoard.sch]
2020-08-01 Laser diode test
2020-08-01 Backend improvements + Frontend generation button
2020-08-03 Steppers visual idea
2020-08-14 LaserHarp: Notes synthesizing
2020-08-23 LaserHarp code to be tested
2020-09-07 LaserHarp more or less working (not autoplaying)
2020-12-25 Laser holder and arduino fixes
    [laserholder.blend, laserholder.stl]
